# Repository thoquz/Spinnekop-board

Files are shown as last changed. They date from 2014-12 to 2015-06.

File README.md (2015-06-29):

# Spinnekop-board
### A minimalist development board for 8-pin ATtiny series chips from Atmel.
---

Basic useful feature list:

 * Designed to be put on the edge of a breadboard, thus taking up minimal space for prototyping.
 * Acts as a breakout board for surface-mount ATtiny chips, each pin is directly broken out the same as the chip's topology.
 * Can be easily made at home, only a single layer of copper traces and 8 components. (including connectors)
 * Supports the ATtiny13/45/85 chips.
 * A programming port. (6-pin ICSP)
 * A linear voltage regulator for powering the board externally. (The LM78L05 can be swapped with a LP2950)

The board is designed in [KiCAD](www.kicad-pcb.org)

The [example code](https://github.com/thoquz/Spinnekop-board/blob/master/example%20code/examplePWM.c) requires the [avr-gcc compiler](https://gcc.gnu.org/wiki/avr-gcc).

Compiling and flashing the code on a Debian-based distro:

```Shell
sudo apt-get install gcc-avr binutils-avr gdb-avr avr-libc avrdude
make
make flash
```
If the last command fails, change the PROGRAMMER variable in the Makefile to match your programming device.
Consult the avrdude man page for the name of your programming device.

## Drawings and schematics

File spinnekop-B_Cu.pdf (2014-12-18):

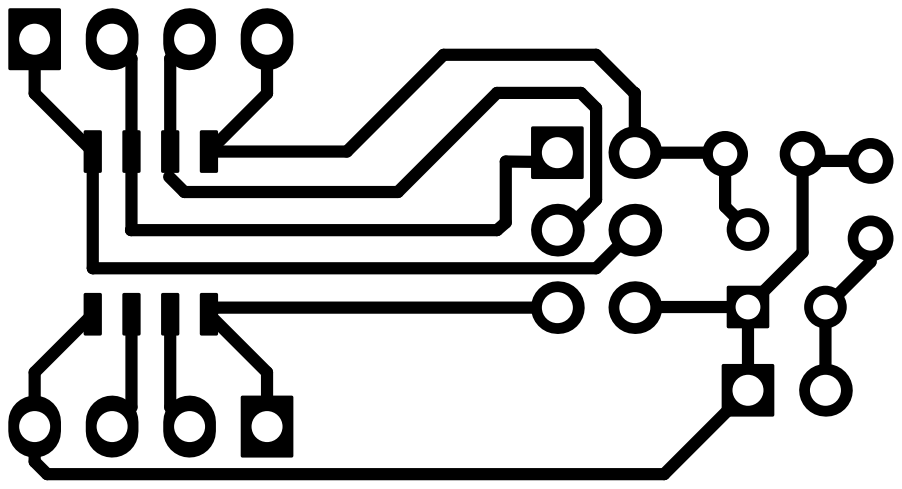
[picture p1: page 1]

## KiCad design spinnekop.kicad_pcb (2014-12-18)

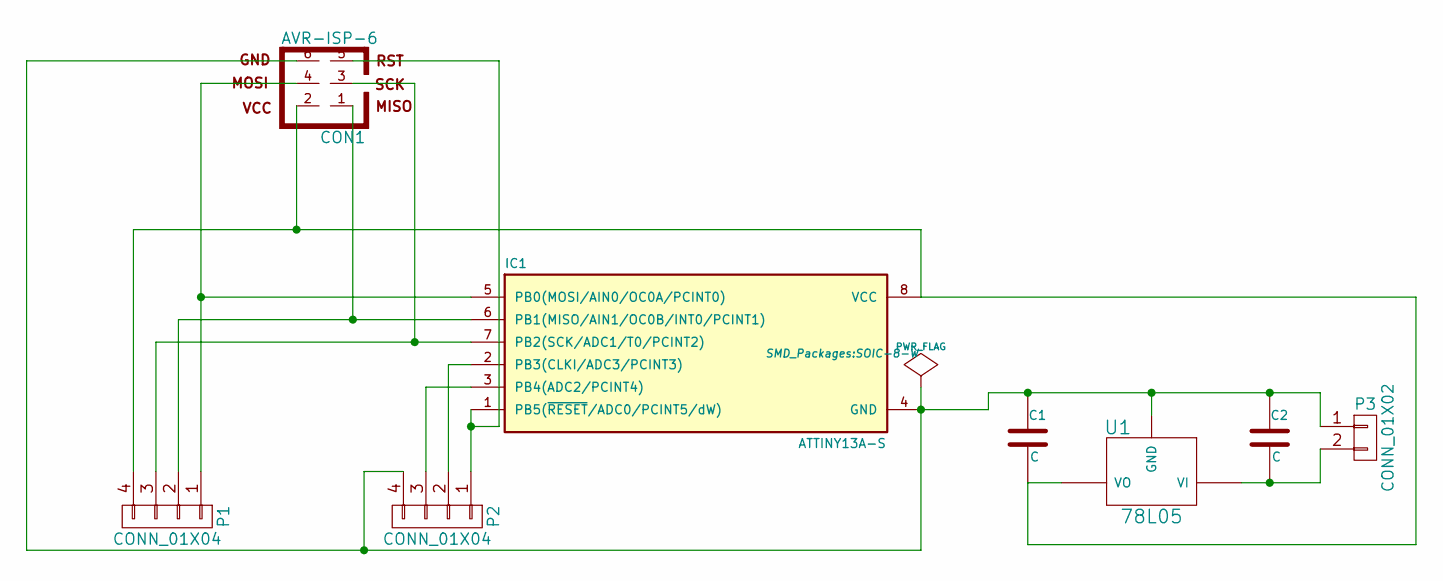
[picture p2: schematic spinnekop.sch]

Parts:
C1, C2: C; Capacitor3MMDiscRM2.5
CON1: AVR-ISP-6; Pin_Header_Straight_2x03
IC1: ATTINY13A-S; SOIC-8-W
P1, P2: CONN_01X04; Pin_Header_Straight_1x04
P3: CONN_01X02; Pin_Header_Straight_2x01
U1: 78L05; LM78LXX

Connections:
unnamed: C1.1, C2.1, CON1.6, IC1.4 (GND), P2.4, P3.1, U1.GND
unnamed: C1.2, CON1.2, IC1.8 (VCC), P1.4, U1.VO
unnamed: C2.2, P3.2, U1.VI
unnamed: CON1.1, IC1.6 (PB1(MISO/AIN1/OC0B/INT0/PCINT1)), P1.2
unnamed: CON1.3, IC1.7 (PB2(SCK/ADC1/T0/PCINT2)), P1.3
unnamed: CON1.4, IC1.5 (PB0(MOSI/AIN0/OC0A/PCINT0)), P1.1
unnamed: CON1.5, IC1.1 (PB5(~RESET~/ADC0/PCINT5/dW)), P2.1
unnamed: IC1.2 (PB3(CLKI/ADC3/PCINT3)), P2.2
unnamed: IC1.3 (PB4(ADC2/PCINT4)), P2.3

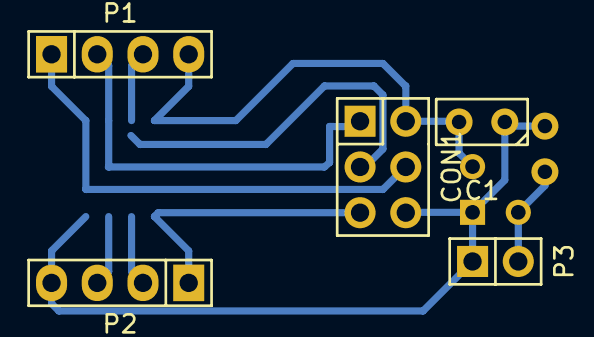
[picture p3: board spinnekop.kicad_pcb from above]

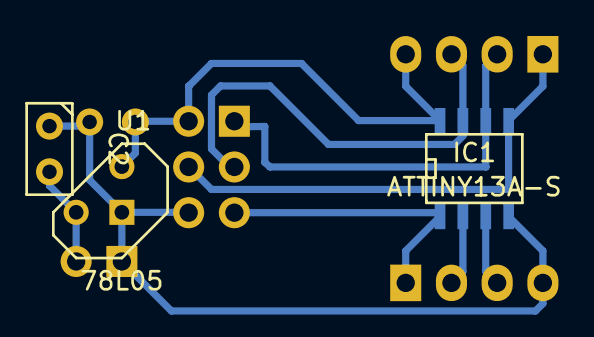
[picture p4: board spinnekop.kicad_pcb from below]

Board: 2 copper layers, 8 parts (3 on the bottom side), 9 nets.

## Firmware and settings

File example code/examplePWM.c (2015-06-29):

/*
 This is free and unencumbered software released into the public domain.

Anyone is free to copy, modify, publish, use, compile, sell, or
distribute this software, either in source code form or as a compiled
binary, for any purpose, commercial or non-commercial, and by any
means.

In jurisdictions that recognize copyright laws, the author or authors
of this software dedicate any and all copyright interest in the
software to the public domain. We make this dedication for the benefit
of the public at large and to the detriment of our heirs and
successors. We intend this dedication to be an overt act of
relinquishment in perpetuity of all present and future rights to this
software under copyright law.

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
For more information, please refer to <http://unlicense.org/>

An example program (For the spinnekop-board) that fades the LED at PB1
between HIGH and LOW state. (Breathing light effect)
Example usage: The board can be connected to the power LED pin inside 
a desktop computer 

([VCC --> LED+] & [GND --> LED-] of the board pins instead of the LED),

Then the LED inside the case can be connected to the spinnekop-board 

([LED+ --> PB0] & [LED- --> GND] of the LED pins onto the board)

PB0 is pin 5 on the microcontroller.
The LED on the desktop's case will now fade in a breathing pattern,
with a board implanted between the LED and the motherboard to create
the effect. 

Made by Philip Goosen
*/

#define F_CPU 9600000 // 9.6MHz with internal oscillator
#define TIMEW 1024 // Sets the rate of the fading effect.

#include <avr/io.h>
#include <util/delay_basic.h>

void setup_pwm()
{
	//prescaler
	TCCR0B |= (1 << CS01) | (1 << CS00);

	//fast pwm
	TCCR0A |= (1 << WGM01) | (1 << WGM00);
	TCCR0A |= (1 << COM0B1);
}

void write_pwm(int val)
{
	OCR0B = val;
}



int main(void)
{
	int val;

	DDRB |= (1 << PB1); // Set LED as output on PB1 

	setup_pwm();


	while(1)
		{
			for(val = 0; val < 255; val++) // Increases the brightness
			{
				write_pwm(val);
				_delay_loop_2(TIMEW);
			}
			
			for(val = 255; val > 0; val--) // Decreases the brightness
			{
				write_pwm(val);
				_delay_loop_2(TIMEW);
			}
		}
}
